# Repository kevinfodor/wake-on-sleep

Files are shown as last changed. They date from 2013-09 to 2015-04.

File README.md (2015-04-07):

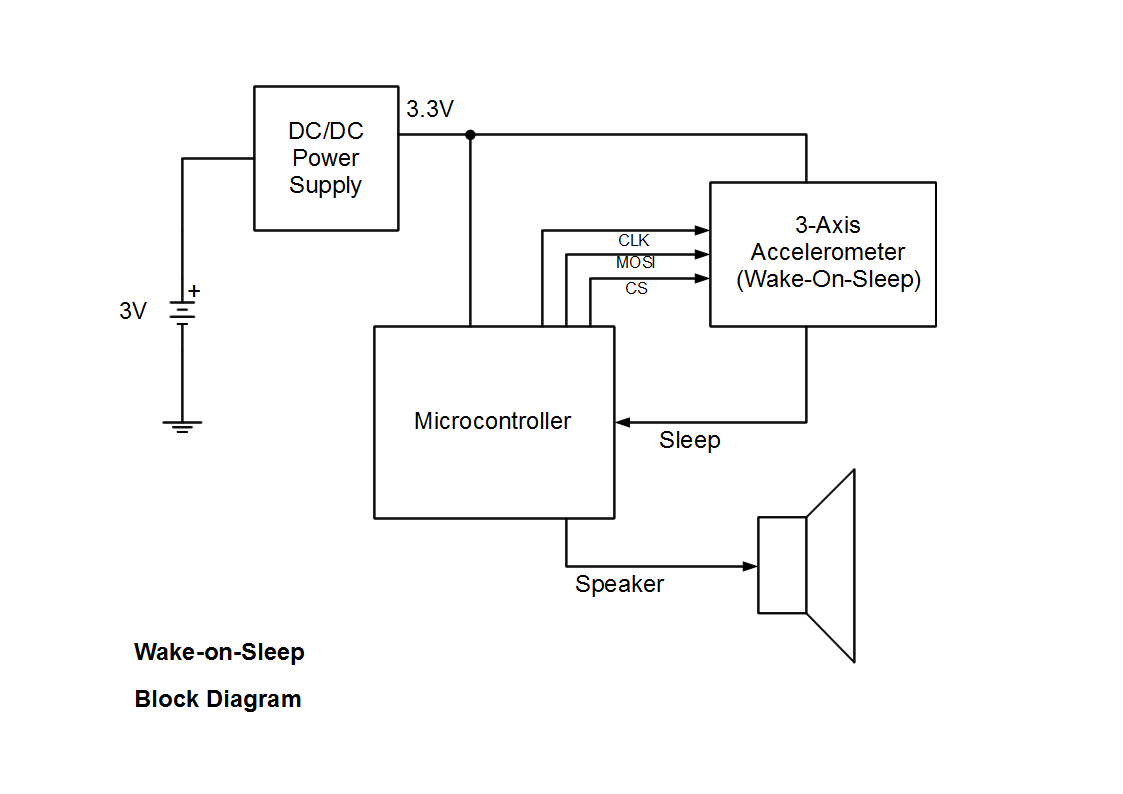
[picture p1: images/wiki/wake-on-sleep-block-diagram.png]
https://raw.githubusercontent.com/kevinfodor/wake-on-sleep/master/images/wiki/wake-on-sleep-block-diagram.png


This project is an implementation of a Wake-On-Sleep device. The idea is that this device will remain idle while it is being played with (motion/activity is detected). However when it has become idle for a period of time, it will wake-up and sound an alert. If someone plays with the device, the alert is cancelled. If nobody acknowledges the device (remains idle) it finally goes back to sleep.

This project is based on the [Wake-On-Shake](https://www.sparkfun.com/products/11447) project, based on a concept by Nitzan Gadish of Analog Devices.
Although the behavior in this case is somewhat opposite. As long as someone is using the device (playing with it) it remains idle. It wakes once someone stops playing with it, sounding an alarm. Thus the name; Wake-On-Sleep.

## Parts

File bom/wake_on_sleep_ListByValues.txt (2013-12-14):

Qty	Value	Part Num	Package	Parts	Mfg Name	VID	Vendor Part Num	Description	Customer Ref	XREF
3	0.1uF	C0603C104M4RACTU	C0603	C3, C4, C5	Kemet	ME	80-C0603C104M4R	Multilayer Ceramic Capacitors MLCC - SMD/SMT 16volts 0.1uF X7R 20%	*	REF149
3	1K	RK73H1JTTD1001F	R0603R	R2, R3, R7	KOA Speer	ME	660-RK73H1JTTD1001F	Thick Film Resistors - SMD 1/10watts 1Kohms 1%	*	REF198
2	1uF	C0603C105K8RACTU	C0603	C1, C2	Kemet	ME	80-C0603C105K8R	Multilayer Ceramic Capacitors MLCC - SMD/SMT 10volts 1uF 10% X7R	*	REF188
1	10K	RK73H1JTTD1002F	R0603R	R1	KOA Speer	ME	660-RK73H1JTTD1002F	Thick Film Resistors - SMD 1/10watts 10Kohms 1%	*	REF199
3	100	RK73H1JTTD1000F	R0603R	R4, R5, R6	KOA Speer	ME	660-RK73H1JTTD1000F	Thick Film Resistors - SMD 1/10watts 100ohms 1%	*	REF200
1	ADP160	ADP160AUJZ-3.3-R7	SOT23-5	U2	Analog Devices	ME	584-ADP160AUJZ-3.3R7	Linear Regulators - Standard Ultra Low Quiescent Crnt 150mA CMOS	*	REF190
1	ADXL362	ADXL362BCCZ-RL	ADXL362_EXT	U3	Analog Devices	ME	584-ADXL362BCCZ-R	Board Mount Acceleration Sensors Micropower 3-Axis Digital Output MEMS	*	REF194
1	BUZZERPTH	254-EMB140-R0	BUZZER-12MM	SG1	Kobitone	ME	254-EMB140-R0	Audio Indicators & Alerts 12 x 8.5mm 2048Hz	*	REF201
1	CR2032-20MM	BA2032SM	BATTCON_20MM_SMD_EJECT	BAT1	MPD	DK	BA2032SM-ND	HOLDER COIN CELL 2032 EJECT SMD	*	REF203
1	EXPANSION	SM04B-SRSS-TB(LF)(SN)(P)	1X04-1MM-RA	JP2	JST	DK	455-1804-1-ND	CONN HEADER SH 4POS SIDE 1MM TIN	*	REF202
1	EXT_PWR	826936-2	JP1	JP3	TE Connectivity / AMP	ME	571-826936-2	Headers & Wire Housings 2P SINGLE ROW	*	REF58
3	GREEN	LTST-C191KGKT	CHIPLED_0603	LED1, LED2, LED3	Lite-On	ME	859-LTST-C191KGKT	Standard LED - SMD Green Clear 571nm	*	REF35
1	ICSP	5-146128-4	1X06_SMD_MALE	JP1	TE Connectivity/AMP	ME	571-5-146128-4	Headers & Wire Housings 06P HDR SR SMT B/A	*	REF195
1	MBR0530	MBR0530	SOD-123	D1	Fairchild Semiconductor	ME	512-MBR0530	Schottky Diodes & Rectifiers Schottky diode 0V/0.5A SOD-123	*	REF193
3	MMBT3904	MMBT3904	SOT23	Q1, Q2, Q3	Fairchild Semiconductor	ME	512-MMBT3904	Transistors Bipolar - BJT SOT-23 NPN GEN PUR	*	REF131
1	PIC16F1823ST	PIC16F1823-I/ST	TSSOP14	U1	Microchip	ME	579-PIC16F1823-I/ST	8-bit Microcontrollers - MCU 3.5KB 128B RAM 32MHz Int. Osc 12 I/0	*	REF189

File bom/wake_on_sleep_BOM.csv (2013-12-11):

Qty-1 | Part References | Value | Package | Mfg Part Num | Mfg Name | VID | Vendor Part Num | Description | Customer Ref | XREF
3 | C3, C4, C5 | 0.1uF | C0603 | C0603C104M4RACTU | Kemet | ME | 80-C0603C104M4R | Multilayer Ceramic Capacitors MLCC - SMD/SMT 16volts 0.1uF X7R 20% | * | REF149
3 | R2, R3, R7 | 1K | R0603R | RK73H1JTTD1001F | KOA Speer | ME | 660-RK73H1JTTD1001F | Thick Film Resistors - SMD 1/10watts 1Kohms 1% | * | REF198
2 | C1, C2 | 1uF | C0603 | C0603C105K8RACTU | Kemet | ME | 80-C0603C105K8R | Multilayer Ceramic Capacitors MLCC - SMD/SMT 10volts 1uF 10% X7R | * | REF188
1 | R1 | 10K | R0603R | RK73H1JTTD1002F | KOA Speer | ME | 660-RK73H1JTTD1002F | Thick Film Resistors - SMD 1/10watts 10Kohms 1% | * | REF199
3 | R4, R5, R6 | 100 | R0603R | RK73H1JTTD1000F | KOA Speer | ME | 660-RK73H1JTTD1000F | Thick Film Resistors - SMD 1/10watts 100ohms 1% | * | REF200
1 | U2 | ADP160 | SOT23-5 | ADP160AUJZ-3.3-R7 | Analog Devices | ME | 584-ADP160AUJZ-3.3R7 | Linear Regulators - Standard Ultra Low Quiescent Crnt 150mA CMOS | * | REF190
1 | U3 | ADXL362 | ADXL362_EXT | ADXL362BCCZ-RL | Analog Devices | ME | 584-ADXL362BCCZ-R | Board Mount Acceleration Sensors Micropower 3-Axis Digital Output MEMS | * | REF194
1 | SG1 | BUZZERPTH | BUZZER-12MM | 254-EMB140-R0 | Kobitone | ME | 254-EMB140-R0 | Audio Indicators & Alerts 12 x 8.5mm 2048Hz | * | REF201
1 | BAT1 | CR2032-20MM | BATTCON_20MM_SMD_EJECT | BA2032SM | MPD | DK | BA2032SM-ND | HOLDER COIN CELL 2032 EJECT SMD | * | REF203
1 | JP2 | EXPANSION | 1X04-1MM-RA | SM04B-SRSS-TB(LF)(SN)(P) | JST | DK | 455-1804-1-ND | CONN HEADER SH 4POS SIDE 1MM TIN | * | REF202
1 | JP3 | EXT_PWR | JP1 | 826936-2 | TE Connectivity / AMP | ME | 571-826936-2 | Headers & Wire Housings 2P SINGLE ROW | * | REF58
3 | LED1, LED2, LED3 | GREEN | CHIPLED_0603 | LTST-C191KGKT | Lite-On | ME | 859-LTST-C191KGKT | Standard LED - SMD Green Clear 571nm | * | REF35
1 | JP1 | ICSP | 1X06_SMD_MALE | 5-146128-4 | TE Connectivity/AMP | ME | 571-5-146128-4 | Headers & Wire Housings 06P HDR SR SMT B/A | * | REF195
1 | D1 | MBR0530 | SOD-123 | MBR0530 | Fairchild Semiconductor | ME | 512-MBR0530 | Schottky Diodes & Rectifiers Schottky diode 0V/0.5A SOD-123 | * | REF193
3 | Q1, Q2, Q3 | MMBT3904 | SOT23 | MMBT3904 | Fairchild Semiconductor | ME | 512-MMBT3904 | Transistors Bipolar - BJT SOT-23 NPN GEN PUR | * | REF131
1 | U1 | PIC16F1823ST | TSSOP14 | PIC16F1823-I/ST | Microchip | ME | 579-PIC16F1823-I/ST | 8-bit Microcontrollers - MCU 3.5KB 128B RAM 32MHz Int. Osc 12 I/0 | * | REF189

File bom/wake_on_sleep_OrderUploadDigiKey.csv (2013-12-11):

Digi-Key Part No. | Manufacturer Name | Mfr Part No. | Customer Reference | Qty1
BA2032SM-ND | MPD | BA2032SM | REF203 | 1
455-1804-1-ND | JST | SM04B-SRSS-TB(LF)(SN)(P) | REF202 | 1

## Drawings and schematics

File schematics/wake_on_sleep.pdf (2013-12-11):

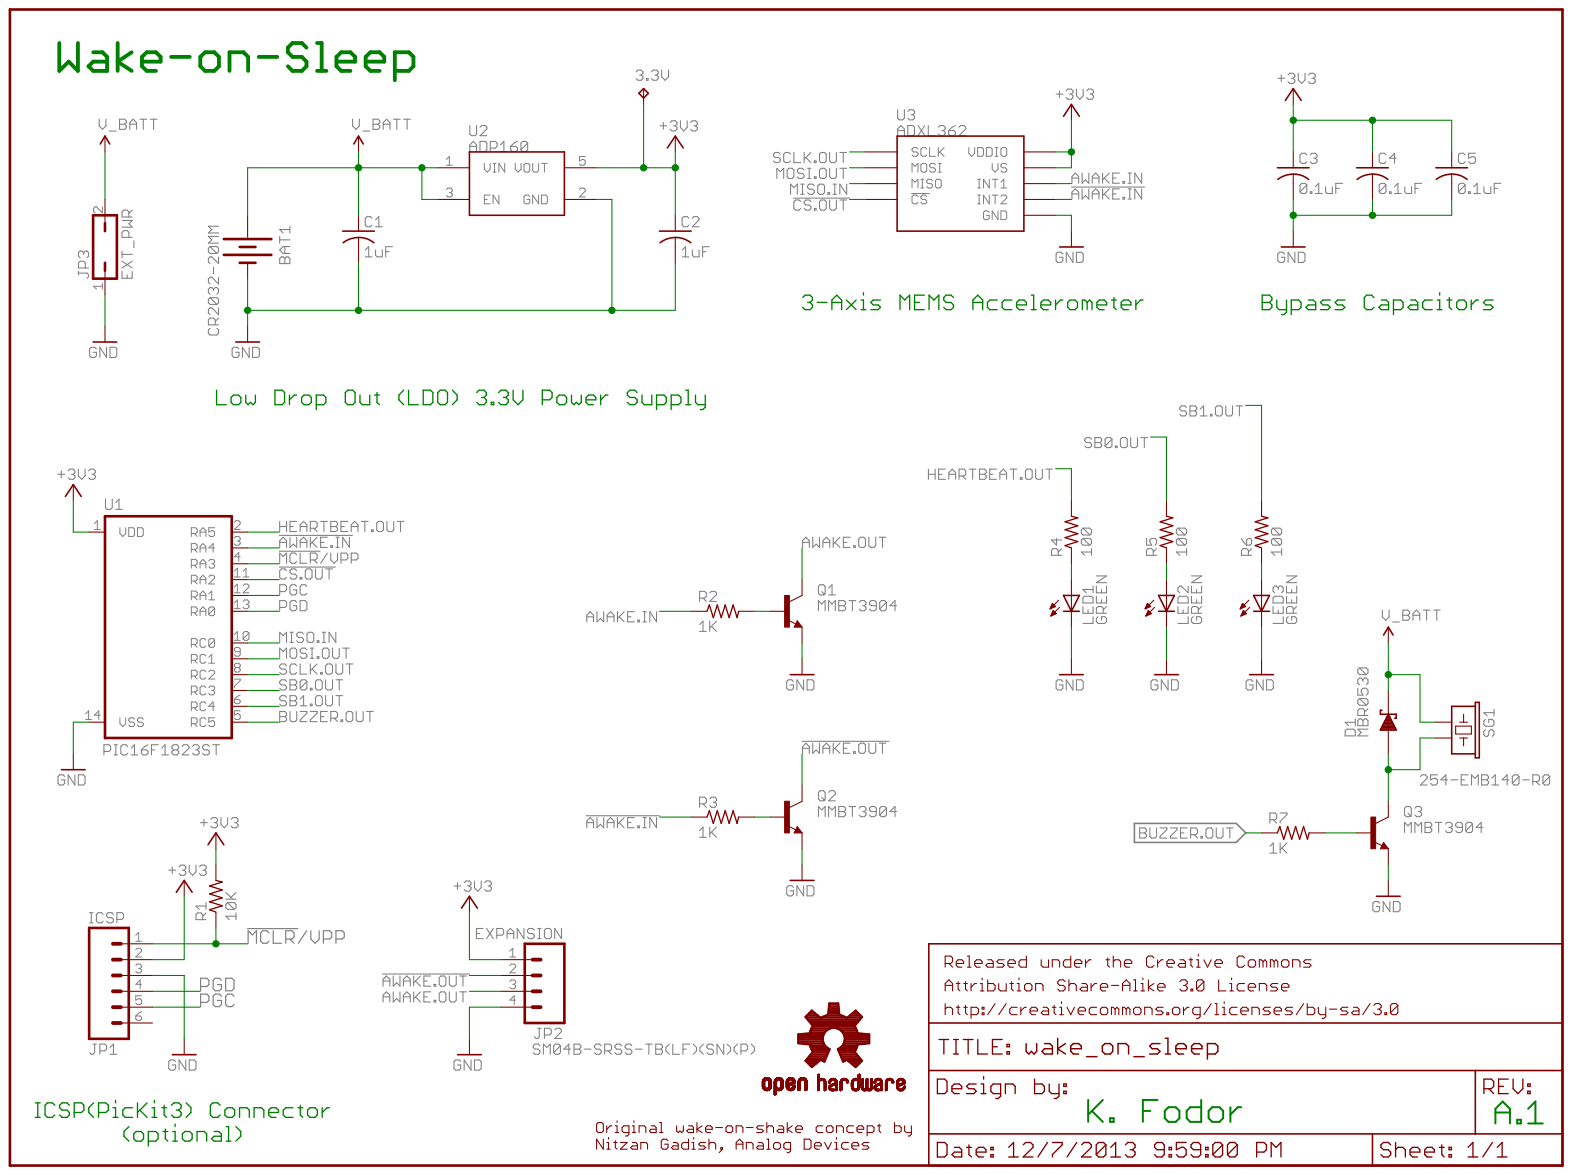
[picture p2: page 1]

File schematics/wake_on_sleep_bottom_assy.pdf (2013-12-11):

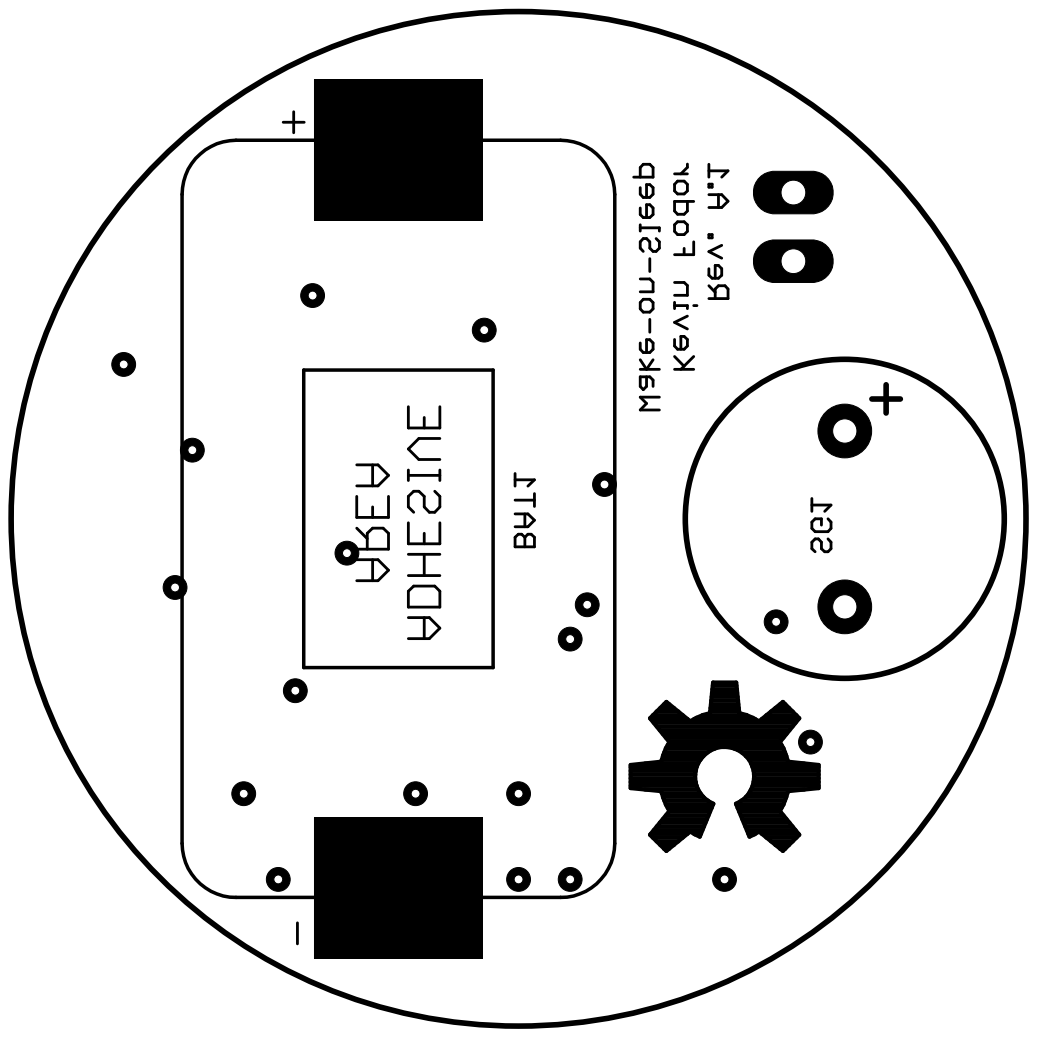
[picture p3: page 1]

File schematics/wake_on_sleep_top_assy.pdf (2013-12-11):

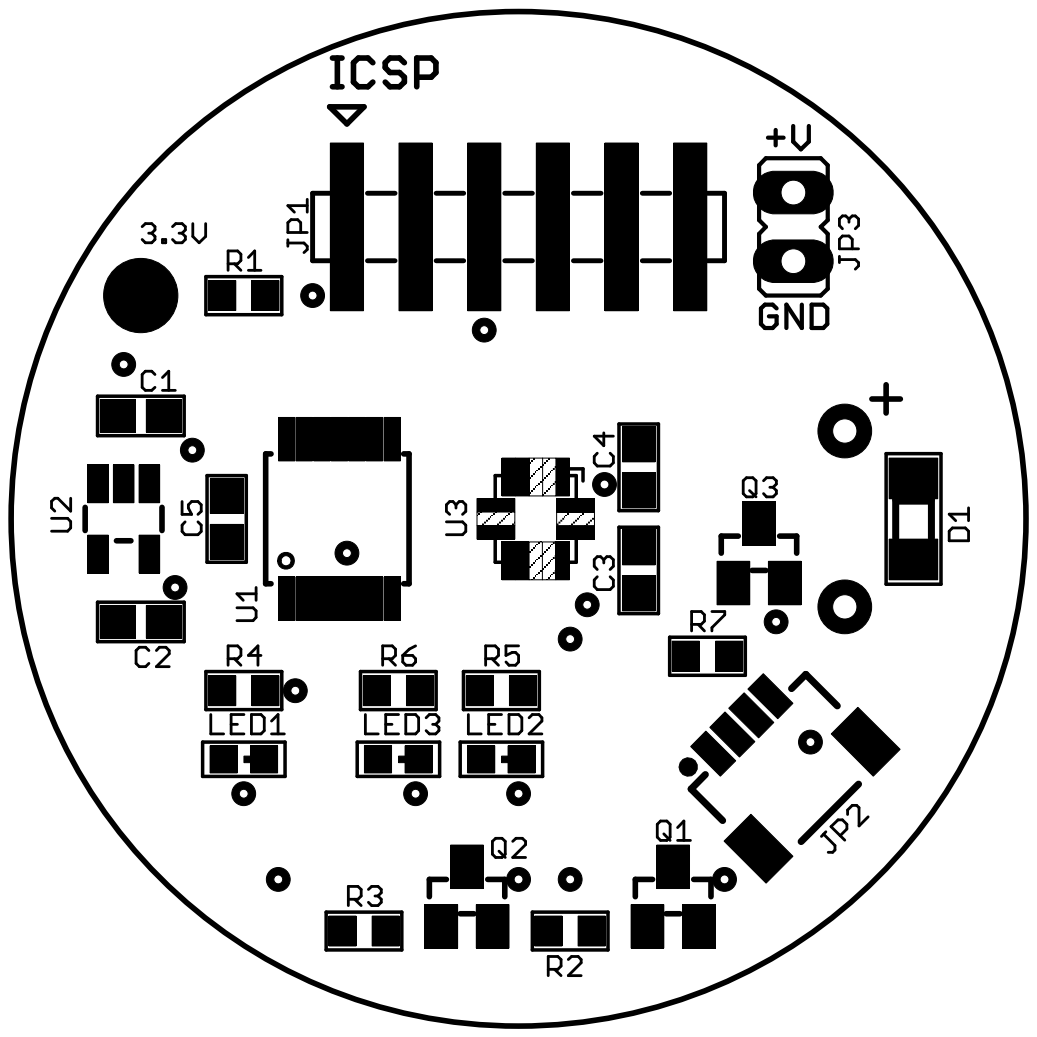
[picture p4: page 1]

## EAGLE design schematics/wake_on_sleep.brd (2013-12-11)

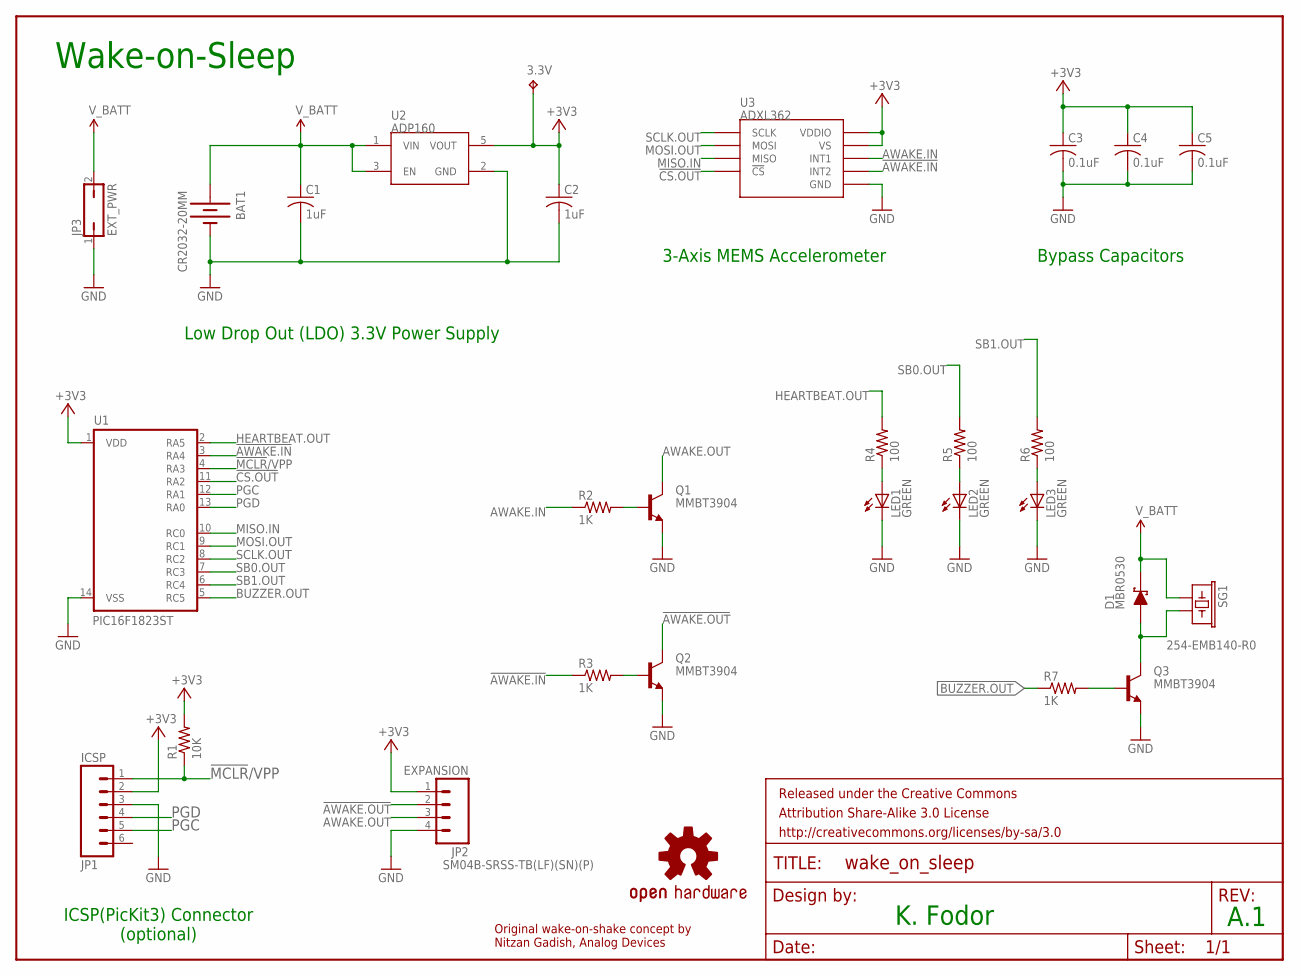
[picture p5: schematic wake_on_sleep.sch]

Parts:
3.3V: TPB2,54; B2,54
BAT1: CR2032-20MM; BATTCON_20MM_SMD_EJECT; PARTNO BA2032SM
C1, C2: 1uF; C0603; PARTNO C0603C105K8RACTU
C3, C4, C5: 0.1uF; C0603; PARTNO C0603C104M4RACTU
D1: MBR0530; SOD-123; PARTNO MBR0530
FRAME1: FRAME-LETTER; CREATIVE_COMMONS
JP1: ICSP; 1X06_SMD_MALE; PARTNO 5-146128-4
JP2: EXPANSION; 1X04-1MM-RA; PARTNO SM04B-SRSS-TB(LF)(SN)(P)
JP3: EXT_PWR; JP1; PARTNO 826936-2
LED1, LED2, LED3: GREEN; CHIPLED_0603; PARTNO LTST-C191KGKT
LOGO1: OSHW-LOGOL; OSHW-LOGO-L
Q1, Q2, Q3: MMBT3904; SOT23; PARTNO MMBT3904
R1: 10K; R0603R; PARTNO RK73H1JTTD1002F
R2, R3, R7: 1K; R0603R; PARTNO RK73H1JTTD1001F
R4, R5, R6: 100; R0603R; PARTNO RK73H1JTTD1000F
SG1: BUZZERPTH; BUZZER-12MM; PARTNO 254-EMB140-R0
U1: PIC16F1823ST; TSSOP14; PARTNO PIC16F1823-I/ST
U2: ADP160; SOT23-5; PARTNO ADP160AUJZ-3.3-R7
U3: ADXL362; ADXL362_EXT; PARTNO ADXL362BCCZ-RL

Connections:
!AWAKE.IN: R3.1, U1.3 (RA4), U3.P$9 (INT2)
!AWAKE.OUT: JP2.2, Q2.3 (C)
!CS.OUT: U1.11 (RA2), U3.P$8 (!CS)
!MCLR!/VPP: JP1.1, R1.1, U1.4 (RA3)
+3V3: 3.3V.TP, C2.1, C3.1, C4.1, C5.1, JP1.2, JP2.1, R1.2, U1.1 (VDD), U2.5 (VOUT), U3.P$1 (VDDIO), U3.P$14 (VS)
AWAKE.IN: R2.1, U3.P$11 (INT1)
AWAKE.OUT: JP2.3, Q1.3 (C)
BUZZER.OUT: R7.1, U1.5 (RC5)
GND: BAT1.VCC@2 (-), C1.2, C2.2, C3.2, C4.2, C5.2, JP1.3, JP2.4, JP3.1, LED1.C, LED2.C, LED3.C, Q1.2 (E), Q2.2 (E), Q3.2 (E), U1.14 (VSS), U2.2 (GND), U3.P$12 (GND), U3.P$13 (GND), U3.P$16 (GND)
HEARTBEAT.OUT: R4.2, U1.2 (RA5)
MISO.IN: U1.10 (RC0), U3.P$7 (MISO)
MOSI.OUT: U1.9 (RC1), U3.P$6 (MOSI)
unnamed: LED3.A, R6.1
unnamed: LED2.A, R5.1
unnamed: LED1.A, R4.1
unnamed: Q1.1 (B), R2.2
unnamed: D1.A, Q3.3 (C), SG1.- (2)
unnamed: Q3.1 (B), R7.2
unnamed: Q2.1 (B), R3.2
PGC: JP1.5, U1.12 (RA1)
PGD: JP1.4, U1.13 (RA0)
SB0.OUT: R5.2, U1.7 (RC3)
SB1.OUT: R6.2, U1.6 (RC4)
SCLK.OUT: U1.8 (RC2), U3.P$4 (SCLK)
V_BATT: BAT1.VCC@1 (+), C1.1, D1.C, JP3.2, SG1.+ (1), U2.1 (VIN), U2.3 (EN)

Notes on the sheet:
Original wake-on-shake concept by Nitzan Gadish, Analog Devices
ICSP(PicKit3) Connector (optional)
Low Drop Out (LDO) 3.3V Power Supply
3-Axis MEMS Accelerometer
Bypass Capacitors

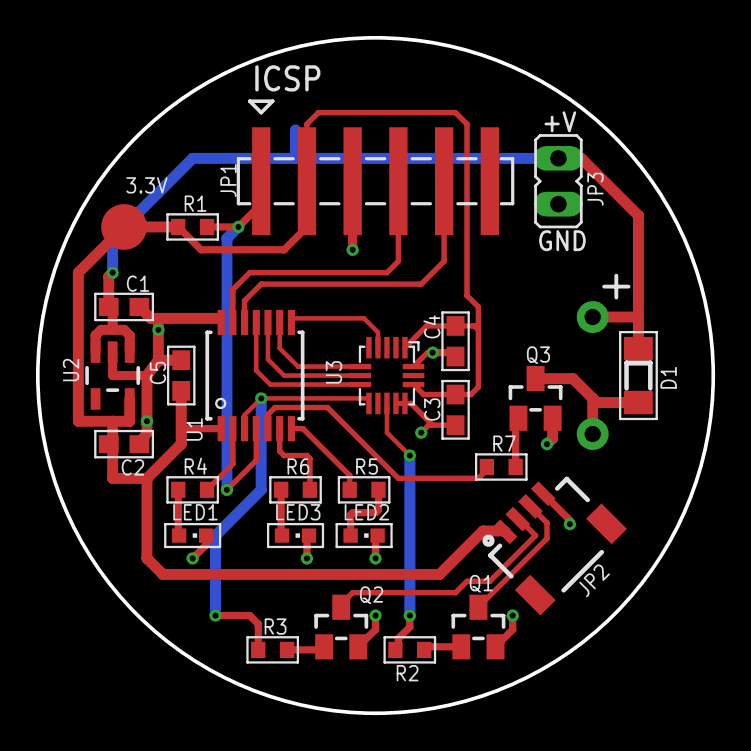
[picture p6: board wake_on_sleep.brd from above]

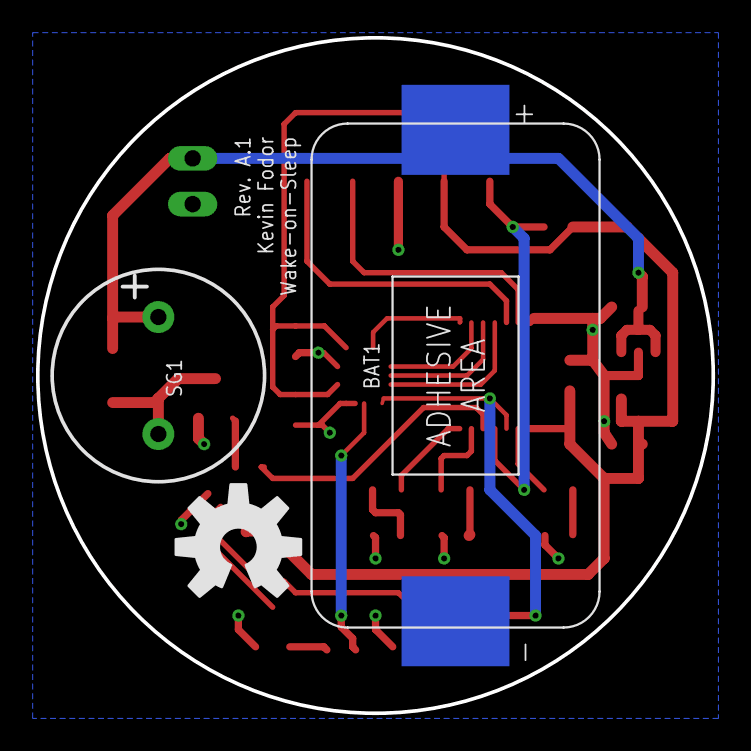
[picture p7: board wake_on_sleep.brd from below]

Board: 2 copper layers, 37.5 x 37.5 mm, 30 parts (3 on the bottom side), 25 nets.

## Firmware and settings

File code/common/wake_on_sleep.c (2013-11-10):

/*
 ==============================================================================
 Name        : wake_on_sleep.c
 Date        : Aug 06, 2013
 ==============================================================================

 BSD License
 -----------

 Copyright (c) 2013, and Kevin Fodor, All rights reserved.

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
 - Redistributions of source code must retain the above copyright notice,
 this list of conditions and the following disclaimer.

 - Redistributions in binary form must reproduce the above copyright notice,
 this list of conditions and the following disclaimer in the documentation
 and/or other materials provided with the distribution.

 - Neither the name of Kevin Fodor nor the names of
 its contributors may be used to endorse or promote products derived from
 this software without specific prior written permission.

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
 NOTICE:
 SOME OF THIS CODE MAY HAVE ELEMENTS TAKEN FROM OTHER CODE WITHOUT ATTRIBUTION.
 IF THIS IS THE CASE IT WAS DUE TO OVERSIGHT WHILE DEBUGGING AND I APOLOGIZE.
 IF ANYONE HAS ANY REASON TO BELIEVE THAT ANY OF THIS CODE VIOLATES OTHER
 LICENSES PLEASE CONTACT ME WITH DETAILS SO THAT I MAY CORRECT THE SITUATION.

 ==============================================================================
 */

// Compiler specific includes
#if defined(__XC)
#include <xc.h>        /* XC8 General Include File */
#elif defined(HI_TECH_C)
#include <htc.h>       /* HiTech General Include File */
#elif defined(__18CXX)
#include <p18cxxx.h>   /* C18 General Include File */
#endif

#if defined(__XC) || defined(HI_TECH_C) || defined (__MINGW32__)

#include <stdint.h>        /* For uint8_t definition */
#include <stdbool.h>       /* For true/false definition */

#endif

#include <stddef.h>

// CPU specific include
#include "../pic/wake_on_sleep.X/user.h"

// Project includes
#include "pwm.h"
#include "adxl362.h"
#include "wake_on_sleep.h"

// Time base defines
#define USEC_PER_TICK (10000) // 10.000 msec

// Common time definitions
#define USEC_PER_SEC    (1000000)
#define MSEC_PER_USEC   (1000)
#define SEC_PER_MSEC    (1000)

// Timeout definitions
#define EXPIRED (0)
#define ALERT_TIMEOUT_USEC                      (10000000)  // 10 sec
#define HEARTBEAT_TIMEOUT_USEC                  (200000)    // 200 msec
#define SOUND_ON_USEC 				(250000)    // 250 msec
#define SOUND_OFF_USEC 				(750000)    // 750 msec
#define INIT_BEEP_USEC                          (125000)    // 125 msec
#define SLEEP_WAIT_USEC                         (500000)    // 500 msec

// Power-on "announcement" beeps
#define NUM_ANNOUNCE_BEEPS (3)

// Timeout counter definitions
#define ONE_SECOND_TIMEOUT_COUNT ((SEC_PER_MSEC * MSEC_PER_USEC) / USEC_PER_TICK)
#define ALERT_TIMEOUT_COUNT (ALERT_TIMEOUT_USEC / USEC_PER_TICK)
#define HEARTBEAT_TIMEOUT_COUNT (HEARTBEAT_TIMEOUT_USEC / USEC_PER_TICK)
#define SOUND_ON_TIMEOUT_COUNT (SOUND_ON_USEC / USEC_PER_TICK)
#define SOUND_OFF_TIMEOUT_COUNT (SOUND_OFF_USEC / USEC_PER_TICK)
#define ANNOUNCE_BEEP_TIMEOUT_COUNT (INIT_BEEP_USEC / USEC_PER_TICK)
#define SLEEP_WAIT_COUNT (SLEEP_WAIT_USEC / USEC_PER_TICK)

/*
 * Controller States.
 */
typedef enum _controller_state_t
{
    // Note: sleep state is defined first
    // since we want the LEDs to be off in this mode.
    controller_sleep = 0,
    controller_init,
    controller_alert,
    controller_unknown

} controller_state_t, *controller_state_ptr_t;

/*
 * Controller state variables.
 */
typedef struct _controller_state_var_t
{
    controller_state_t previous;
    controller_state_t current;
} controller_fsm_state_vars_t, *controller_state_var_ptr_t;

/*
 * Controller state-transition table.
 */
typedef struct _controller_fsm_state_t
{
    // State
    controller_state_t state;

    // Functions
    void (*enter)(void);
    controller_state_t (*run)(void);
    void (*exit)(void);

} controller_fsm_tabel_t, *controller_fsm_state_ptr_t;

/*
 * Controller init state-data.
 */
typedef struct _controller_init_state_data_t
{
    uint8_t beep_count;
    uint8_t sound_count;
} controller_init_state_data_t, *controller_init_state_data_ptr_t;

/*
 * Controller sleep state-data.
 */
typedef struct _controller_sleep_state_data_t
{
    uint8_t sleep_wait_count;
} controller_sleep_state_data_t, *controller_sleep_state_data_ptr_t;

/*
 * Controller alert state-data.
 */
typedef struct _controller_alert_state_data_t
{
    uint16_t alert_count;
    uint8_t sound_count;
    uint8_t alert_profile_index;
} controller_alert_state_data_t, *controller_alert_state_data_ptr_t;

/*
 * Controller state-data union.
 * All structures here are shared state variables
 * which must be initialized upon state entry.
 */
typedef union _controller_fsm_data_t
{
    controller_init_state_data_t init;
    controller_sleep_state_data_t sleep;
    controller_alert_state_data_t alert;

} controller_fsm_data_t, *controller_fsm_data_ptr_t;

/*
 * Controller finite-state machine definition.
 */
typedef struct _controller_fsm_t
{
    controller_fsm_state_vars_t state;
    controller_fsm_data_t data;
    controller_fsm_tabel_t const * table;
} controller_fsm_t, *controller_fsm_ptr_t;

/*
 * Alert profile structure definition.
 */
typedef struct _alert_profile_t
{
    uint8_t range;
    uint8_t count[2]; // on/off

} alert_profile_t, *alert_profile_ptr_t;

/*
 * Local Function Declarations.
 */

static void update_heartbeat(void);

// init-state prototypes
static void fsm_init_enter(void);
static controller_state_t fsm_init_run(void);
static void fsm_init_exit(void);

// sleep-state prototypes
static void fsm_sleep_enter(void);
static controller_state_t fsm_sleep_run(void);
static void fsm_sleep_exit(void);

// alert-state prototypes
static void fsm_alert_enter(void);
static controller_state_t fsm_alert_run(void);
static void fsm_alert_exit(void);

/*
 * Local static variable declarations.
 */

static const alert_profile_t alert_profile[] =
{
{ 3,
{ SOUND_ON_TIMEOUT_COUNT, SOUND_OFF_TIMEOUT_COUNT } },
{ 1,
{ SOUND_ON_TIMEOUT_COUNT, SOUND_OFF_TIMEOUT_COUNT / 3 } },
{ 0,
{ SOUND_ON_TIMEOUT_COUNT * 4, 0 } } };

static controller_fsm_tabel_t const controller_fsm_table[] =
{
// Note: These must be listed in numerical order by state value.
        { controller_sleep, fsm_sleep_enter, fsm_sleep_run, fsm_sleep_exit },
        { controller_init, fsm_init_enter, fsm_init_run, fsm_init_exit },
        { controller_alert, fsm_alert_enter, fsm_alert_run, fsm_alert_exit } };

static controller_fsm_t controller_fsm;

/*
 * Implementation
 */

/*! \brief update_heartbeat
 */
static void update_heartbeat(void)
{
    static uint16_t heartbeat_count = HEARTBEAT_TIMEOUT_COUNT;

    if (heartbeat_count-- == EXPIRED)
    {
        // Reset heart beat timeout
        heartbeat_count = HEARTBEAT_TIMEOUT_COUNT;

        // Toggle heart beat
        HEARTBEAT_PORT ^= HEARTBEAT;
    }

    return;
}

/*! \brief fsm_init_enter
 */
static void fsm_init_enter(void)
{
    controller_init_state_data_ptr_t init_data = &controller_fsm.data.init;

    // Initialize the PWM module. The PWM module is used
    // to drive the speaker(buzzer)
    pwm_init();

    // Initialize the ADXL362 for autonomous operation
    adxl362_init();

    // Initialize the "Ready Announcement"
    init_data->sound_count = ANNOUNCE_BEEP_TIMEOUT_COUNT;
    init_data->beep_count = NUM_ANNOUNCE_BEEPS;
    pwm_start(); // Start the PWM module.

    return;
}

/*! \brief fsm_init_run
 */
static controller_state_t fsm_init_run(void)
{
    controller_init_state_data_ptr_t init_data = &controller_fsm.data.init;
    controller_state_t state = controller_init;

    // Announce "ready"
    if (init_data->sound_count-- == EXPIRED)
    {
        // Sound on?
        if (pwm_is_on() == true)
        {
            // Sound off
            pwm_stop();

            // One beep generated.
            if (--init_data->beep_count == 0)
            {
                // Transition to the sleep state and wait
                state = controller_sleep;
            }
        }
        else
        {
            // Sound on
            pwm_start();
        }

        // Restart beep-on timer
        init_data->sound_count = ANNOUNCE_BEEP_TIMEOUT_COUNT;
    }

    return state;
}

/*! \brief fsm_init_exit
 */
static void fsm_init_exit(void)
{
    return;
}

/*! \brief fsm_sleep_enter
 */
static void fsm_sleep_enter(void)
{
    controller_sleep_state_data_ptr_t sleep_data = &controller_fsm.data.sleep;

    // Initialize sleep wait timeout
    sleep_data->sleep_wait_count = SLEEP_WAIT_COUNT;

    return;
}

/*! \brief fsm_sleep_run
 */
static controller_state_t fsm_sleep_run(void)
{
    controller_state_t state = controller_sleep;
    controller_sleep_state_data_ptr_t sleep_data = &controller_fsm.data.sleep;

    // Wait for controller to settle
    if (sleep_data->sleep_wait_count-- == EXPIRED)
    {
        // Put accelerometer into auto-sleep mode
        adxl362_autosleep(true);
        
        // Turn off heart beat
        HEARTBEAT_PORT &= ~HEARTBEAT;
        
        // Put controller into sleep mode
        // *** SLEEP until nAWAKE goes high ***
        // *** ZZZzzz...
        nAWAKE_CLEAR; // clear interrupt
        SLEEP();

        // ...huh? I'm awake!
        // We are not active, sound the alert!
        state = controller_alert;
    }

    return state;
}

/*! \brief fsm_sleep_exit
 */
static void fsm_sleep_exit(void)
{
    // Take accelerometer out of auto-sleep mode
    adxl362_autosleep(false);

    // Exit sleep mode
    return;
}

/*! \brief fsm_inactive_enter
 */
static void fsm_alert_enter(void)
{
    controller_alert_state_data_ptr_t alert_data = &controller_fsm.data.alert;

    // Initialize state variables
    alert_data->alert_count = ALERT_TIMEOUT_COUNT;
    alert_data->sound_count = SOUND_ON_TIMEOUT_COUNT;
    alert_data->alert_profile_index = 0;

    // Start the PWM module.
    pwm_start();

    return;
}

/*! \brief fsm_inactive_run
 */
static controller_state_t fsm_alert_run(void)
{
    bool awake;
    controller_state_t state = controller_alert;
    controller_alert_state_data_ptr_t alert_data = &controller_fsm.data.alert;

    // Get current accelerometer state
    awake = !adxl362_is_asleep();

    // Any activity or timeout, go back to sleep
    if ((awake) || (alert_data->alert_count == EXPIRED))
    {
        // Go back to sleep
        state = controller_sleep;
    }
    else
    {
        // Adjust alert timeout counter
        --alert_data->alert_count;

        // Sound timeout?
        if (alert_data->sound_count-- == EXPIRED)
        {
            uint8_t seconds_remaining = (alert_data->alert_count / 100) + 1;

            // Update alert profile
            if ((seconds_remaining
                    <= alert_profile[alert_data->alert_profile_index].range)
                    && (alert_data->alert_profile_index
                            < sizeof(alert_profile) / sizeof(alert_profile_t)))
            {
                // Choose next profile
                alert_data->alert_profile_index++;
            }

            // Sound on?
            if (pwm_is_on() == false)
            {
                // Configure counter and turn on sound.
                alert_data->sound_count =
                        alert_profile[alert_data->alert_profile_index].count[0];
                if (alert_data->sound_count > 0)
                {
                    pwm_start();
                }
            }
            // Sound off
            else
            {
                // Configure counter and turn off sound.
                alert_data->sound_count =
                        alert_profile[alert_data->alert_profile_index].count[1];
                if (alert_data->sound_count > 0)
                {
                    pwm_stop();
                }
            }
        }
    }

    return state;
}

/*! \brief fsm_inactive_exit
 */
static void fsm_alert_exit(void)
{
    // Stop the PWM module.
    pwm_stop();

    return;
}

/*! \brief main
 */
int main(void)
{

    init();

    // Initialize state variables.
    controller_fsm.state.previous = controller_unknown;
    controller_fsm.state.current = controller_init;

    // Link in state transition table.
    controller_fsm.table = controller_fsm_table;

    do
    {
        // Wait for periodic timeout
        while (!TIMER_EXPIRED);
        TIMER_RESET;

        update_heartbeat();

        /*
         * Controller Finite State Machine
         */

        // Entry
        if (controller_fsm.state.previous != controller_fsm.state.current)
        {
            controller_fsm_table[controller_fsm.state.current].enter();
            controller_fsm.state.previous = controller_fsm.state.current;
        }

        // Run
        controller_fsm.state.current =
                controller_fsm_table[controller_fsm.state.current].run();

        // Exit
        if (controller_fsm.state.previous != controller_fsm.state.current)
        {
            controller_fsm_table[controller_fsm.state.previous].exit();
        }

        // Clear and set state bits
        STATE_PORT &= ~STATE_MASK;
        STATE_PORT |=
                ((controller_fsm.state.current & 0x03) << STATE_BITS_SHIFT);

    } while (true);

    return 0;
}

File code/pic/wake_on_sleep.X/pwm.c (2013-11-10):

/*
 ==============================================================================
 Name        : pwm.c
 Date        : Aug 6, 2013
 ==============================================================================

 BSD License
 -----------

 Copyright (c) 2013, and Kevin Fodor, All rights reserved.

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
 - Redistributions of source code must retain the above copyright notice,
 this list of conditions and the following disclaimer.

 - Redistributions in binary form must reproduce the above copyright notice,
 this list of conditions and the following disclaimer in the documentation
 and/or other materials provided with the distribution.

 - Neither the name of Kevin Fodor nor the names of
 its contributors may be used to endorse or promote products derived from
 this software without specific prior written permission.

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
 NOTICE:
 SOME OF THIS CODE MAY HAVE ELEMENTS TAKEN FROM OTHER CODE WITHOUT ATTRIBUTION.
 IF THIS IS THE CASE IT WAS DUE TO OVERSIGHT WHILE DEBUGGING AND I APOLOGIZE.
 IF ANYONE HAS ANY REASON TO BELIEVE THAT ANY OF THIS CODE VIOLATES OTHER
 LICENSES PLEASE CONTACT ME WITH DETAILS SO THAT I MAY CORRECT THE SITUATION.

 ==============================================================================
 */

// Compiler specific includes
#if defined(__XC)
#include <xc.h>        /* XC8 General Include File */
#elif defined(HI_TECH_C)
#include <htc.h>       /* HiTech General Include File */
#elif defined(__18CXX)
#include <p18cxxx.h>   /* C18 General Include File */
#endif

#if defined(__XC) || defined(HI_TECH_C) || defined (__MINGW32__)

#include <stdint.h>        /* For uint8_t definition */
#include <stdbool.h>       /* For true/false definition */

#endif

// Target includes
#include "user.h"

// Module include
#include "pwm.h"

#define PWM_FREQ (2048) // 2.048 kHz

// Local declarations

// Implementation

/*! \brief pwm_init
 */
void pwm_init(void)
{
#if (__18F45K20 == 1) || (_18F45K20 == 1)

    // Set as output so PWM output drives it
    PWM_TRIS = 0;

    // Set up 8-bit Timer2 to generate the PWM period (frequency)
    // Prescale = 4, timer off, postscale not used with CCP module
    T2CONbits.T2OUTPS = 0b0000;
    T2CONbits.TMR2ON = 0b0;
    T2CONbits.T2CKPS = 0b01;

    // Timer 2 Period Register (PR2) = (<clk> / 4 / <prescale> / <freq>) - 1
    // Thus, the PWM frequency is:
    // 8MHz clock / 4 = 2MHz instruction rate.
    // (2MHz / <prescale>) / <PR2+1>)
    PR2 = (FCY / 4 / 2048) - 1;

    // The Duty Cycle is controlled by the ten-bit CCPR1L<7,0>:DC1B1:DC1B0
    // 50% Duty Cycle = 0.5 * (<PR2+1> * 4)
    // The 8 most significant bits of the value are needed here
    CCPR1L = (((((PR2+1) * 2) >> 2)) & 0xFF);

    // P1Mx = 01 Full-Bridge output forward, so we get the PWM
    // signal on P1D to LED7.  Only Single Output (00) is needed,
    // but the P1A pin does not connect to a demo board LED
    // The 2 least significant bits of the value are written
    // to the DC1B1 and DC1B0 bits in CCP1CON
    // CCP1Mx = 1100, PWM mode with P1D active-high.
    CCP1CONbits.P1M = 0b01;
    CCP1CONbits.DC1B = (((PR2+1) * 2) & 0x03);
    CCP1CONbits.CCP1M = 0b1100;

#elif (__16F1823 == 1) || (_16F1823 == 1)

#define TMR2_PRESCALE (1)

    // PWM Period = [(PR2)+ 1] * 4 * Tosc * TMR2PS
    // 1 / PWM_Freq = [(PR2)+ 1] * 4 * (1 / Fosc) * TMR2PS
    // PR2 = (Fosc / (4 * TMR2PS * PWM_Freq)) - 1
#define PWM_PERIOD ((FOSC / (4 * TMR2_PRESCALE * PWM_FREQ)) - 1)

    // Disable the CCP1 pin output driver by setting
    // the associated TRIS bit.
    PWM_TRIS = 1;

    // Load the PR2 register with the PWM period value.
    PR2 = PWM_PERIOD;

    // CCP1CON: CCP1 CONTROL REGISTER
    // Configure the CCP1 module for the PWM mode
    // by loading the CCP1CON register with the
    // appropriate values.

    // The Duty Cycle is controlled by the ten-bit CCPR1L<7,0>:DC1B1:DC1B0
    // 50% Duty Cycle = 1/2 * [(PWM_PERIOD)+ 1] * 4
    // Pulse Width = ([(PWM_PERIOD)+ 1] * 4) / 2
#define PULSE_WIDTH ((((PWM_PERIOD)+ 1) * 4) / 2)

    // Single output; P1A modulated; P1B, P1C, P1D assigned as port pins
    CCP1CONbits.P1M = 0b00;
    // These bits are the two LSbs of the PWM duty cycle. The eight MSbs
    // are found in CCPR1L.
    CCP1CONbits.DC1B = (PULSE_WIDTH & 0x03);
    // PWM mode: P1A, P1C active-high; P1B, P1D active-high
    CCP1CONbits.CCP1M = 0b1100;

    // Load the CCPR1L register and the DC1B1 bits
    // of the CCP1CON register, with the PWM duty
    // cycle value.

    // The 8 most significant bits of the value are needed here
    CCPR1L = ((PULSE_WIDTH >> 2) & 0xFF);

    // Configure and start Timer2:
    // -Clear the TMR2IF interrupt flag bit of the
    //  PIR1 register.
    PIR1bits.TMR2IF = 0;

    // T2CON: TIMER2 CONTROL REGISTER

    // -Configure the T2CKPS bits of the T2CON
    // register with the Timer prescale value.
    T2CONbits.T2CKPS = 0b00;// Prescaler is 1
    // - Enable the Timer by setting the TMR2ON
    // bit of the T2CON register.
    T2CONbits.TMR2ON = 1;// Timer2 is on

    // Set up 8-bit Timer2 to generate the PWM period (frequency)
    // Prescale = 4, timer off, postscale not used with CCP module
    T2CONbits.T2OUTPS = 0b0000;// 1:1 Postscaler

#elif defined __MINGW32__

    // Nothing to configure

#else

#error Error! You must create definitions for this processor.

#endif
    return;
}

/*! \brief pwm_start
 */
void pwm_start(void)
{
#if (__18F45K20 == 1) || (_18F45K20 == 1) || \
    (__16F1823 == 1) || (_16F1823 == 1)

    // Enable the CCP1 pin output driver by clearing
    // the associated TRIS bit.
    PWM_TRIS = 0;

    // Timer 2 on
    T2CONbits.TMR2ON = 1;

#elif defined __MINGW32__

#else

#error Error! You must create definitions for this processor.

#endif
    return;
}

/*! \brief pwm_stop
 */
void pwm_stop(void)
{
#if (__18F45K20 == 1) || (_18F45K20 == 1) || \
    (__16F1823 == 1) || (_16F1823 == 1)

    // Check if the timer is on
    if(T2CONbits.TMR2ON == 1)
    {
        // Wait until the Timer overflows and the TMR2IF bit of the PIR1
        // register is set.
        while (PIR1bits.TMR2IF == 0);

        // Disable the CCP1 pin output driver by setting
        // the associated TRIS bit.
        PWM_TRIS = 1;

        // Timer 2 off
        T2CONbits.TMR2ON = 0;
    }

#elif defined __MINGW32__

#else

#error Error! You must create definitions for this processor.

#endif
    return;
}

/*! \brief pwm_is_on
 */
int pwm_is_on(void)
{
#if (__18F45K20 == 1) || (_18F45K20 == 1) || \
    (__16F1823 == 1) || (_16F1823 == 1)

    // Return timer state
    return (T2CONbits.TMR2ON == 1);

#elif defined __MINGW32__

    return false;
#else

#error Error! You must create definitions for this processor.

#endif
}

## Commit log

2013-11-10 Initial drop
    [wake_on_sleep.brd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]
2013-12-11 Updated to Rev A.1 and prepared for PCB build
    [wake_on_sleep.brd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]
2013-12-14 Updated BOM
2014-10-24 schematics/eagle.epf view changes

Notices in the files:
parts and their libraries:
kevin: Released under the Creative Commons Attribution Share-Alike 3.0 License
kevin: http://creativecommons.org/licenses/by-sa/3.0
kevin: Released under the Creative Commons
